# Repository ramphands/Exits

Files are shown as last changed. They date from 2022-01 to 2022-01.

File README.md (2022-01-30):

# Exits
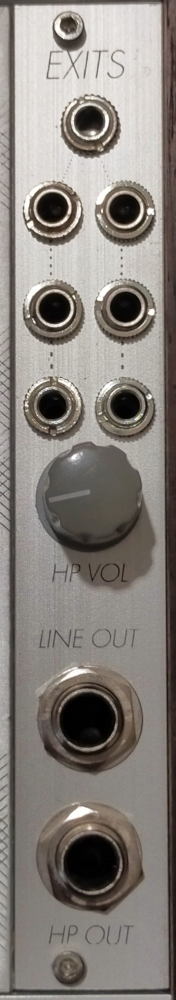
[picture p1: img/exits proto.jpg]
exits


4hp DIY eurorack line and headphone output module based on the [Nearness](https://github.com/sarnesjo/nearness) and [Forestcaver headphone amp](https://github.com/forestcaver/Analog-Voice/tree/master/AJH_Headphone_Amp) designs

The Nearness section is a "minimal panning mixer for the Eurorack modular synthesizer system. Seven inputs, two outputs. The closer an input is to an output, the greater its influence on it."  
The Forestcaver headphone amp is a "NJM4556 based headphone amp. This is essentially the power section from the nwavguy o2 headphone amp. It has a very low output impedance (~1 ohm) so can drive even low impedance headphones. It can deliver a high power (utilising two sections of the njm4556 per channel) so can drive 600 ohm impedance headphones with no problem. There is a high pass filter on the input to block dc."

These have been combined in a single 4hp module which utilises 6.35mm stereo jacks for both the line and headphone outputs.  

## Schematic and PCBs

The [kicad](kicad) directory contains the schematic and PCB layout as a KiCad 6 project.

## Panel

Available in the [panel](panel) directory as a PDF and an SVG vector file.

## Revisions and notes 

This version is an updated version of my original prototype.  Notable changes as follows:
- Updated pin header widths to improve security/stability between the two boards.
- Changed the type of jacks used for the output to a more widely-available device, the SJ-63083A.
- Adjusted positioning of the potentiometer to provide more space between the shaft and the nearest input jacks.
- Reversed the headphone and line output jacks to the more logical orientation; headphone jack is nearest the headphone volume knob
### Please note that these changes, while minor, have not been tested, so build at your own risk.

## License

[CC BY-SA 4.0](http://creativecommons.org/licenses/by-sa/4.0/)

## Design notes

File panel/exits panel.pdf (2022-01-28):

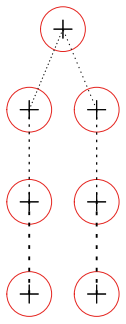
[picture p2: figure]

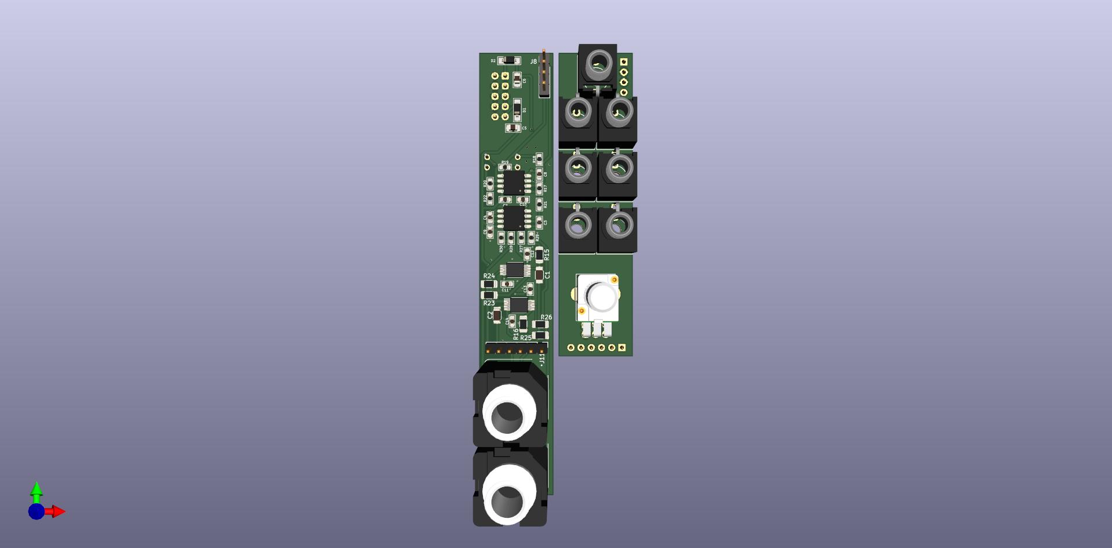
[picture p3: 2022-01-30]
img/exits 3d.jpg

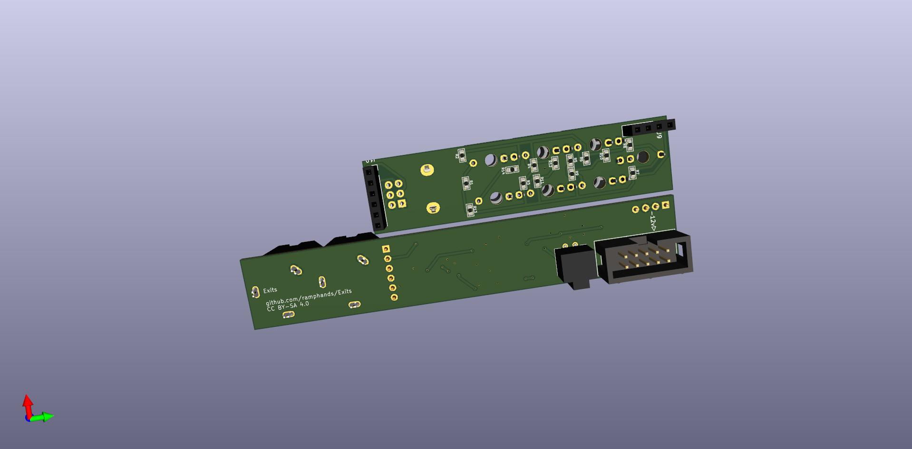
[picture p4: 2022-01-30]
img/exits btm 3d.jpg

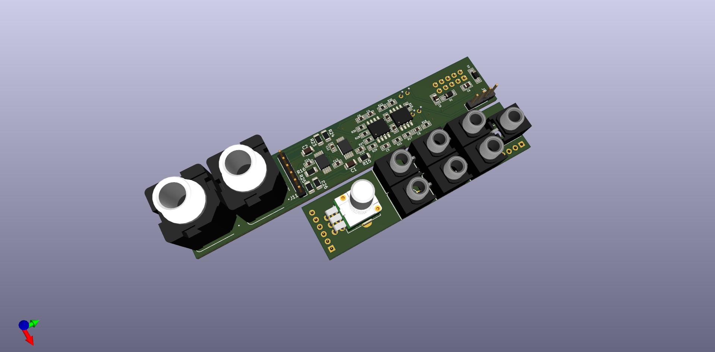
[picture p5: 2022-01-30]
img/exits top 3d.jpg

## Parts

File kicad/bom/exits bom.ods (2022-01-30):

EXITS Bill of Materials
Ref | Qnty | Value | Footprint | Tolerance | Description | Vendor
RESISTORS
R1, R14, R17, R18, R19, R20, R21, R22, R27, R28, | 10 | 100k | 0603 | 0.1% 25ppm | Resistor | 652-CRT0603BY1003ELF (https://www.mouser.jp/ProductDetail/652-CRT0603BY1003ELF)
R2, R13, | 2 | 1M69 | 0603 | 0.1% 25ppm | Resistor | 71-CRCW06031M69FKEA (https://www.mouser.jp/ProductDetail/71-CRCW06031M69FKEA)
R3, R12, | 2 | 102k | 0603 | 0.1% 25ppm | Resistor | 667-ERA-3AEB1023V (https://www.mouser.jp/ProductDetail/667-ERA-3AEB1023V)
R4, R11, | 2 | 442k | 0603 | 0.1% 25ppm | Resistor | 603-RT0603BRD07442KL (https://www.mouser.jp/ProductDetail/603-RT0603BRD07442KL)
R5, R10, | 2 | 113k | 0603 | 0.1% 25ppm | Resistor | 667-ERA-3AEB1133V (https://www.mouser.jp/ProductDetail/667-ERA-3AEB1133V)
R6, R9, | 2 | 215k | 0603 | 0.1% 25ppm | Resistor | 667-ERA-3AEB2153V (https://www.mouser.jp/ProductDetail/667-ERA-3AEB2153V)
R7, R8, | 2 | 140k | 0603 | 0.1% 25ppm | Resistor | 667-ERA-3AEB1403V (https://www.mouser.jp/ProductDetail/667-ERA-3AEB1403V)
R15, R16, | 2 | 100k | 1206 | 0.1% 25ppm | Resistor | 71-TNPW1206100KBEEA (https://www.mouser.jp/ProductDetail/71-TNPW1206100KBEEA)
R23, R24, R25, R26, | 4 | 1r | 1206 | 1% 1/2W (500mW) | Resistor | 652-CRS1206AFX1R00LF (https://www.mouser.jp/ProductDetail/652-CRS1206AFX1R00LF)
R29, R30, | 2 | 1k | 0603 | 0.1% 25ppm | Resistor | 667-ERA-3AEB102V (https://www.mouser.jp/ProductDetail/667-ERA-3AEB102V)
CAPACITORS
C1, C2, | 2 | 100n | 1206 | C0G/NP0, 2% >25v | Unpolarized capacitor | GRM31C5C1E104GA01L (https://www.mouser.jp/ProductDetail/Murata-Electronics/GRM31C5C1E104GA01L?qs=lqAf%2FiVYw9i8LI7bf9C68Q%3D%3D)
C3, C4, | 2 | 22p | 0603 | C0G/NP0, 2% >25v | Unpolarized capacitor | 791-0603N220G500CT (https://www.mouser.jp/ProductDetail/791-0603N220G500CT)
C5, C6, | 2 | 22u | 0805 | X5R >25v | Unpolarized capacitor | CL21A226MAQNNNF (https://www.mouser.jp/ProductDetail/Samsung-Electro-Mechanics/CL21A226MAQNNNF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)
C7, C8, C9, C10, C11, C12, C13, C14, | 8 | 100n | 0603 | X7R 10% >25v | Unpolarized capacitor | CL10B104KA8NNND (https://www.mouser.jp/ProductDetail/Samsung-Electro-Mechanics/CL10B104KA8NNND?qs=349EhDEZ59p2BVyIlRF8Uw%3D%3D)
DIODES
D1, D2, | 2 | 1N5819HW | SOD-123 |  | Diode | 621-1N5819HW-7-F (https://www.mouser.jp/ProductDetail/Diodes-Incorporated/1N5819HW-7-F?qs=NQ47qNm99eDyWTEd07miYA%3D%3D)
ICs
IC1, IC2, | 2 | NJM4556AV-TE1 | SSOP-8 |  | Operational Amplifiers - Op Amps Dual High Current | 513-NJM4556AV-TE1 (https://www.mouser.jp/ProductDetail/Nisshinbo/NJM4556AV-TE1)
U3, U4, | 2 | LME49720 | SOIC-8 |  | high-fidelity, high performance audio op amp 8-SOIC | 926-LME49720MAX/NOPB (https://www.mouser.jp/ProductDetail/Texas-Instruments/LME49720MAX-NOPB)
 |  |  |  |  | ALTERNATIVES TO LME49720 | 926-LM4562MA/NOPB (https://www.mouser.jp/ProductDetail/926-LM4562MA-NOPB) | 926-LM4562MAX/NOPB (https://www.mouser.jp/ProductDetail/926-LM4562MAX-NOPB)
POTS
RV1, | 1 | 50k A | R_POT_Dual_Separate | Potentiometer_THT:Potentiometer_Alpha_RD902F-40-00D_Dual_Vertical | Dual potentiometer, separate units | Thonk A50K dual gang (https://www.thonk.co.uk/shop/alpha-9mm-pots-dshaft/)
THROUGH-HOLE
J1, J2, J3, J4, J5, J6, J7, J8, J9 | 9 | Jack, PJ301M-12 |  |  |  |  | https://www.thonk.co.uk/shop/3-5mm-jacks/
J13, J15, | 2 | SJ-63083A | SJ-63083A |  | Audio Jack, 3 Poles (Stereo / TRS) | 490-SJ-63083A (https://www.mouser.jp/ProductDetail/CUI-Devices/SJ-63083A)
S1, | 1 | ADP0204 | ADP0204 |  | DIP Switches / SIP Switches SPST 2P PIANO T/H DIP SWITCH | 506-ADP0204 (https://www.mouser.jp/ProductDetail/TE-Connectivity-PB/ADP0204)
J8, | 1 | Conn_01x04_Male | Connector_PinHeader_2.54mm:PinHeader_1x04_P2.54mm_Vertical
J9, | 1 | Conn_01x04_Female | Connector_PinSocket_2.54mm:PinSocket_1x04_P2.54mm_Vertical
J10, | 1 | Conn_01x06_Female | Connector_PinSocket_2.54mm:PinSocket_1x06_P2.54mm_Vertical
J11, | 1 | Conn_01x06_Male | Connector_PinHeader_2.54mm:PinHeader_1x06_P2.54mm_Vertical
J12, | 1 | Eurorack Power Header | Connector_IDC:IDC-Header_2x05_P2.54mm_Vertical |  | 2x10 shrouded header

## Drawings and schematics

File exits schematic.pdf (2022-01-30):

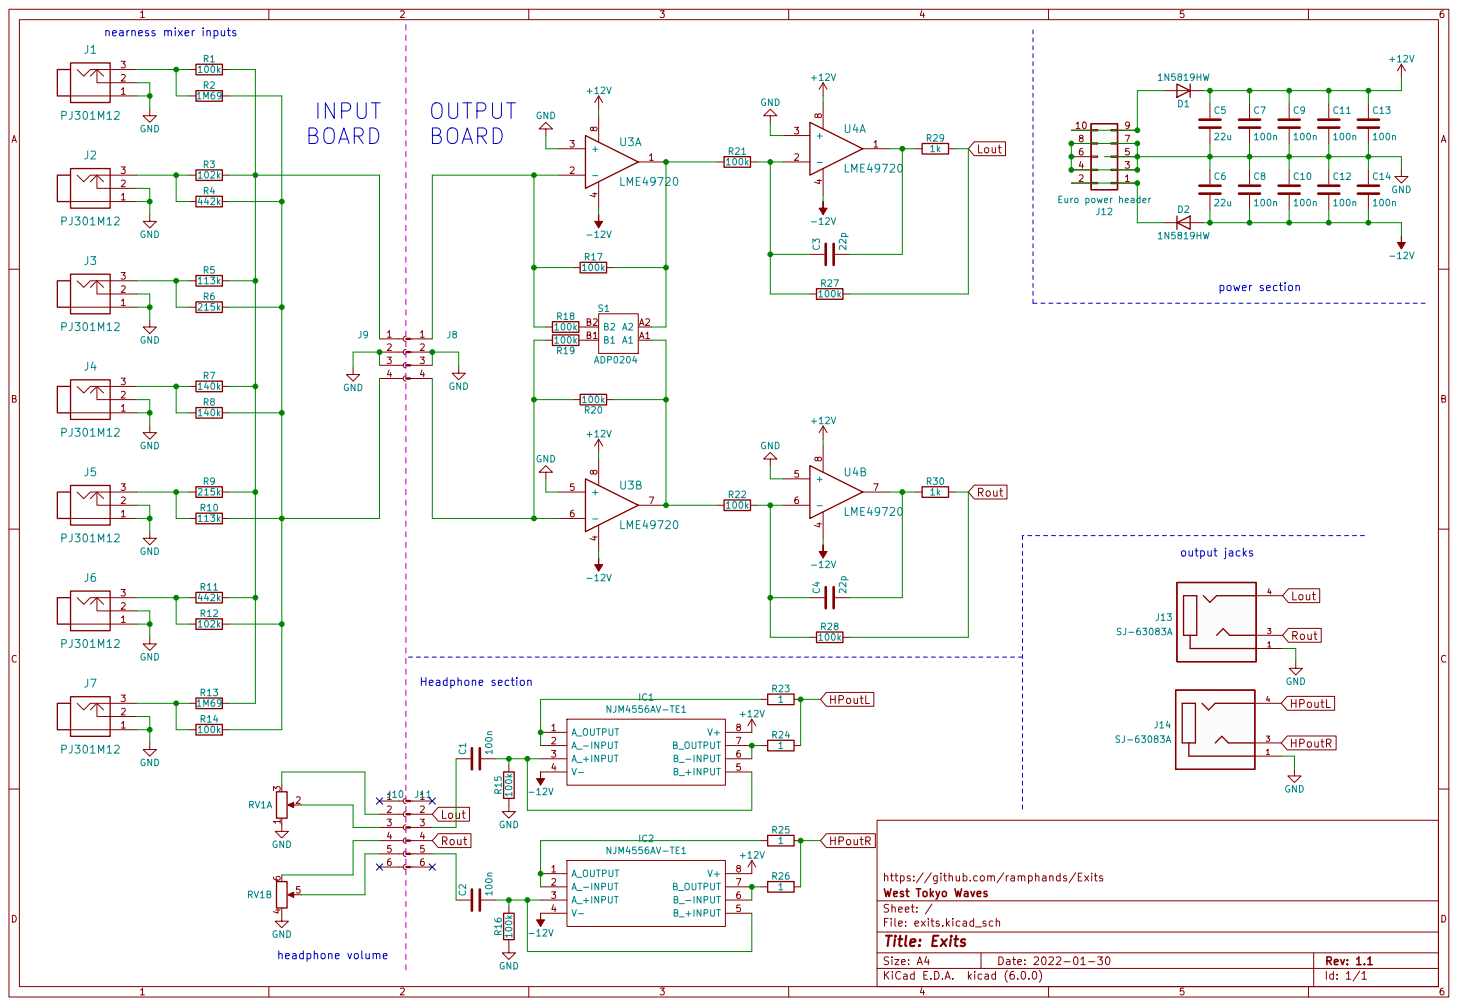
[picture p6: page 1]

https://github.com/ramphands/Exits GND

File: exits.kicad_sch Sheet: / West Tokyo Waves

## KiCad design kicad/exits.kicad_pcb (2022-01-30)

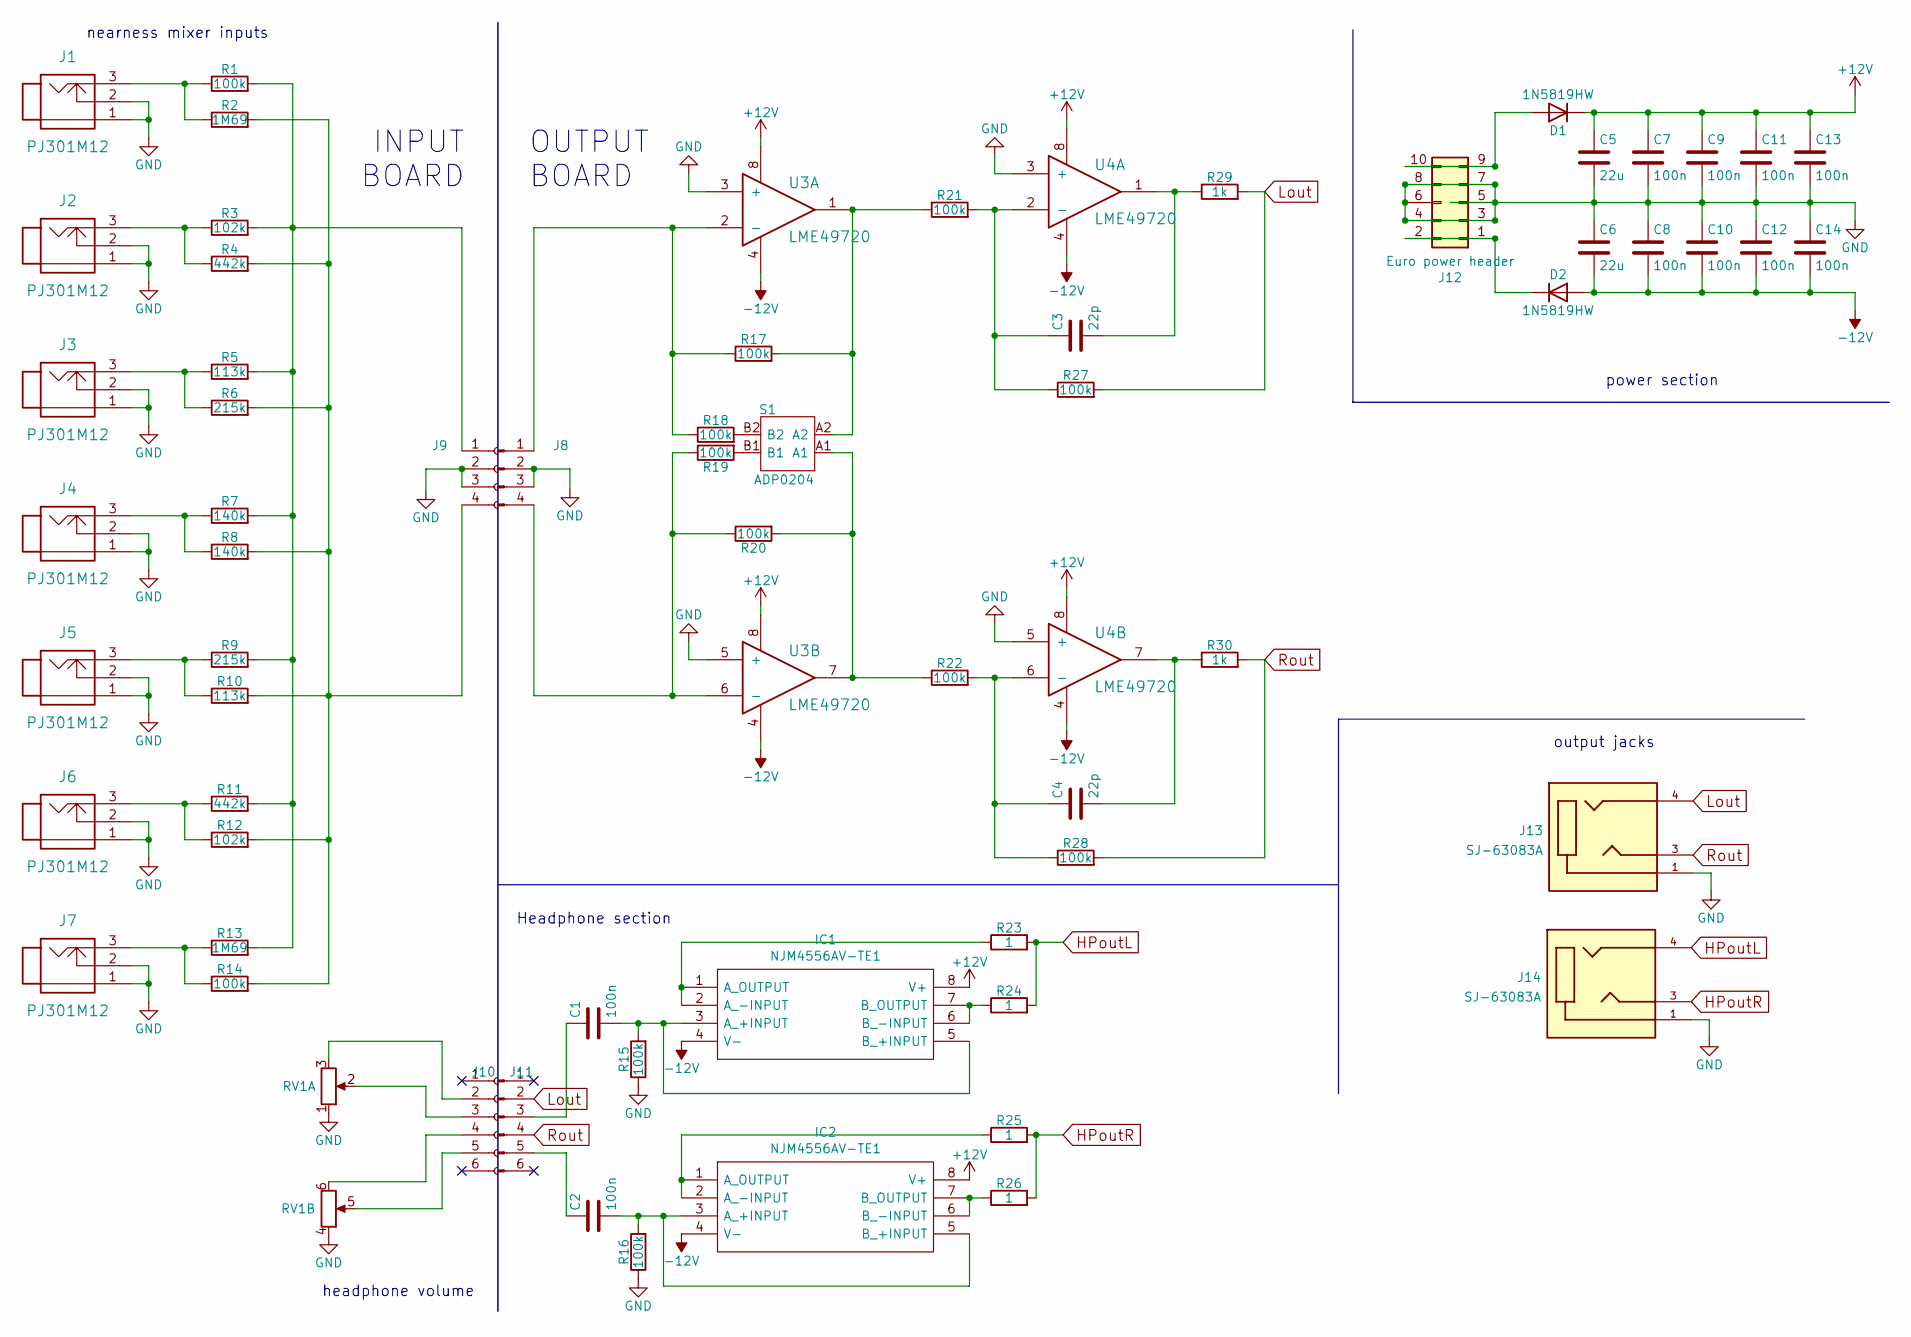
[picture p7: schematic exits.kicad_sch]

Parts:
C1, C2: 100n; C_1206
C3, C4: 22p; 0603
C5, C6: 22u; 0805
C7, C8, C9, C10, C11, C12, C13, C14: 100n; 0603
D1, D2: 1N5819HW; SOD-123
IC1, IC2: NJM4556AV-TE1; SOP65P640X145-8N; Mouser Part Number 513-NJM4556AV-TE1
J1, J2, J3, J4, J5, J6, J7: PJ301M12
J8: Conn_01x04_Male; PinHeader_1x04_P2.54mm_Vertical
J9: Conn_01x04_Female; PinSocket_1x04_P2.54mm_Vertical
J10: Conn_01x06_Female; PinSocket_1x06_P2.54mm_Vertical
J11: Conn_01x06_Male; PinHeader_1x06_P2.54mm_Vertical
J12: Euro power header; IDC-Header_2x05_P2.54mm_Vertical
J13, J14: SJ-63083A; CUI_SJ-63083A; PARTREV 1.0
R1, R14, R17, R18, R19, R20, R21, R22, R27, R28: 100k; 0603
R2, R13: 1M69; 0603
R3, R12: 102k; 0603
R4, R11: 442k; 0603
R5, R10: 113k; 0603
R6, R9: 215k; 0603
R7, R8: 140k; 0603
R15, R16: 100k; R_1206_3216Metric
R23, R24, R25, R26: 1; R_1206_3216Metric
R29, R30: 1k; 0603
RV1: 50k A; Potentiometer_Alpha_RD902F-40-00D_Dual_Vertical
S1: ADP0204; Mouser Part Number 506-ADP0204
U3, U4: LME49720; SOIC-8

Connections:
+12V: C5.1, C7.1, C9.1, C11.1, C13.1, D1.1 (K), IC1.8 (V+), IC2.8 (V+), U3.8, U4.8
-12V: C6.2, C8.2, C10.2, C12.2, C14.2, D2.2 (A), IC1.4 (V-), IC2.4 (V-), U3.4, U4.4
GND: C5.2, C6.1, C7.2, C8.1, C9.2, C10.1, C11.2, C12.1, C13.2, C14.1, J1.1, J1.2, J2.1, J2.2, J3.1, J3.2, J4.1, J4.2, J5.1, J5.2, J6.1, J6.2, J7.1, J7.2, J8.2, J8.3, J9.2, J9.3, J12.3, J12.4, J12.5, J12.6, J12.7, J12.8, J13.1, J14.1, R15.1, R16.1, RV1.1, RV1.4, U3.3 (+), U3.5 (+), U4.3 (+), U4.5 (+)
HPoutL: J14.4, R23.2, R24.2
HPoutR: J14.3, R25.2, R26.2
Lout: J11.2, J13.4, R27.2, R29.2
unnamed: C1.1, J11.3
unnamed: C1.2, IC1.3 (A_+INPUT), IC1.5 (B_+INPUT), R15.2
unnamed: C2.1, J11.5
unnamed: C2.2, IC2.3 (A_+INPUT), IC2.5 (B_+INPUT), R16.2
unnamed: C3.1, R21.2, R27.1, U4.2 (-)
unnamed: C3.2, R29.1, U4.1
unnamed: C4.1, R22.2, R28.1, U4.6 (-)
unnamed: C4.2, R30.1, U4.7
unnamed: D1.2 (A), J12.9, J12.10
unnamed: D2.1 (K), J12.1, J12.2
unnamed: IC1.1 (A_OUTPUT), IC1.2 (A_-INPUT), R23.1
unnamed: IC1.6 (B_-INPUT), IC1.7 (B_OUTPUT), R24.1
unnamed: IC2.1 (A_OUTPUT), IC2.2 (A_-INPUT), R25.1
unnamed: IC2.6 (B_-INPUT), IC2.7 (B_OUTPUT), R26.1
unnamed: J1.3, R1.1, R2.1
unnamed: J2.3, R3.1, R4.1
unnamed: J3.3, R5.1, R6.1
unnamed: J4.3, R7.1, R8.1
unnamed: J5.3, R9.1, R10.1
unnamed: J6.3, R11.1, R12.1
unnamed: J7.3, R13.1, R14.1
unnamed: J8.1, R17.1, R18.1, U3.2 (-)
unnamed: J8.4, R19.1, R20.1, U3.6 (-)
unnamed: J9.1, R1.2, R3.2, R5.2, R7.2, R9.2, R11.2, R13.2
unnamed: J9.4, R2.2, R4.2, R6.2, R8.2, R10.2, R12.2, R14.2
unnamed: J10.2, RV1.3
unnamed: J10.3, RV1.2
unnamed: J10.4, RV1.6
unnamed: J10.5, RV1.5
unnamed: R17.2, R21.1, S1.A2, U3.1
unnamed: R18.2, S1.B2
unnamed: R19.2, S1.B1
unnamed: R20.2, R22.1, S1.A1, U3.7
Rout: J11.4, J13.3, R28.2, R30.2

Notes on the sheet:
headphone volume
INPUT BOARD
Headphone section
OUTPUT BOARD
output jacks
nearness mixer inputs
power section

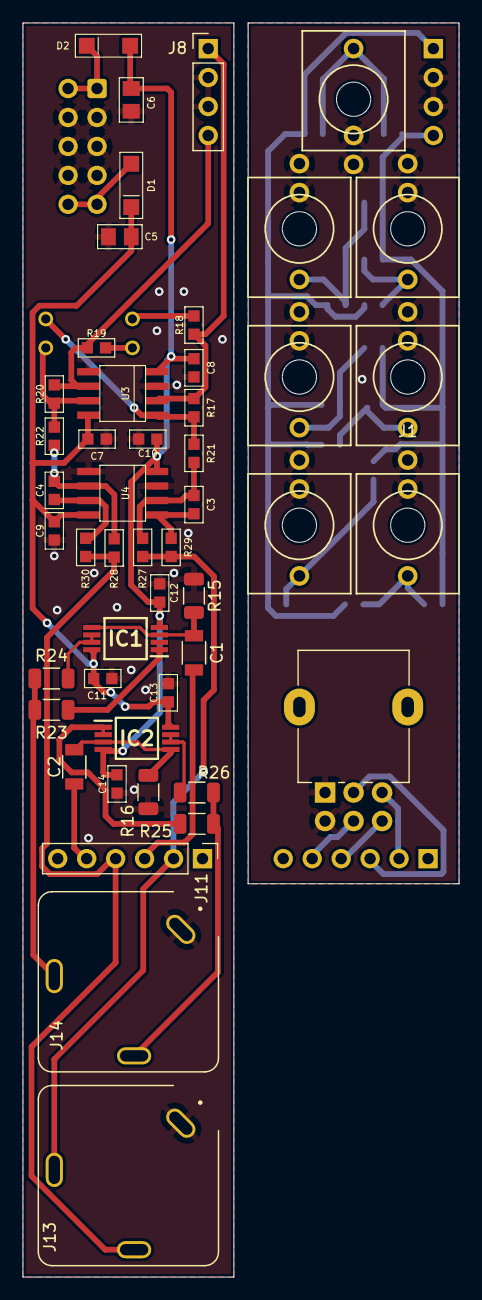
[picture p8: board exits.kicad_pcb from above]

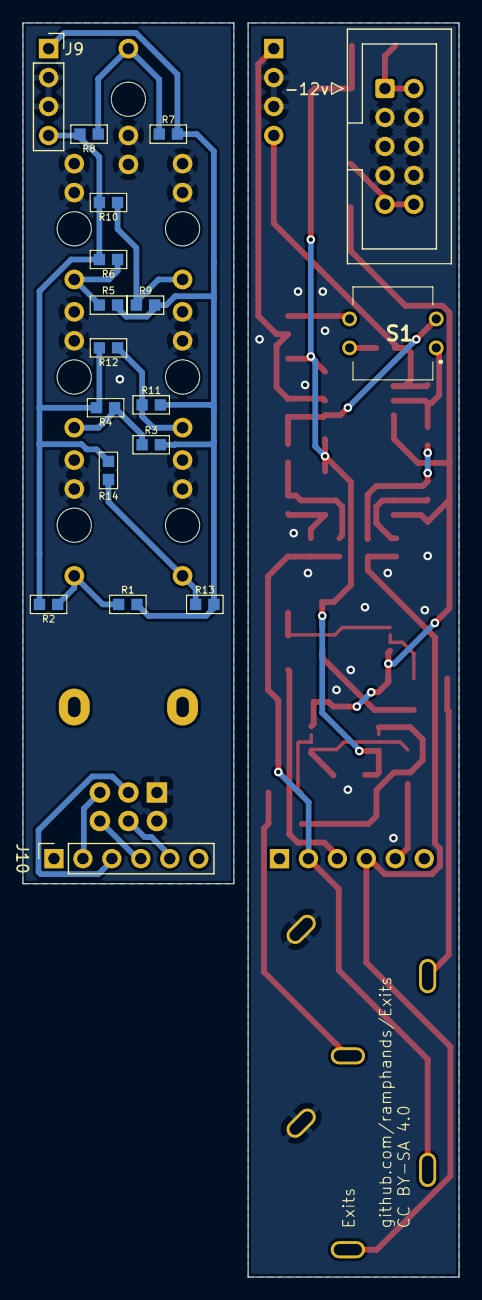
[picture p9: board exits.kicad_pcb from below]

Board: 2 copper layers, 38.2 x 110.0 mm, 66 parts (18 on the bottom side), 40 nets.

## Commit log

2022-01-27 Add files via upload
    Contains schematics, PCB designs, associated footprints and symbols.
    Also contains gerbers for the two boards in the subfolder.
    [exits board A-B_Cu.gbr, exits board A-B_Mask.gbr, exits board A-B_Silkscreen.gbr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]
2022-01-27 Add files via upload
    prototype version
2022-01-27 Add files via upload
    image of the original prototype
2022-01-30 Add files via upload
    Contains BOM as a .ODS file (with Mouser links) and an interactive BOM (iBOM)
    [exits bom.ods]
